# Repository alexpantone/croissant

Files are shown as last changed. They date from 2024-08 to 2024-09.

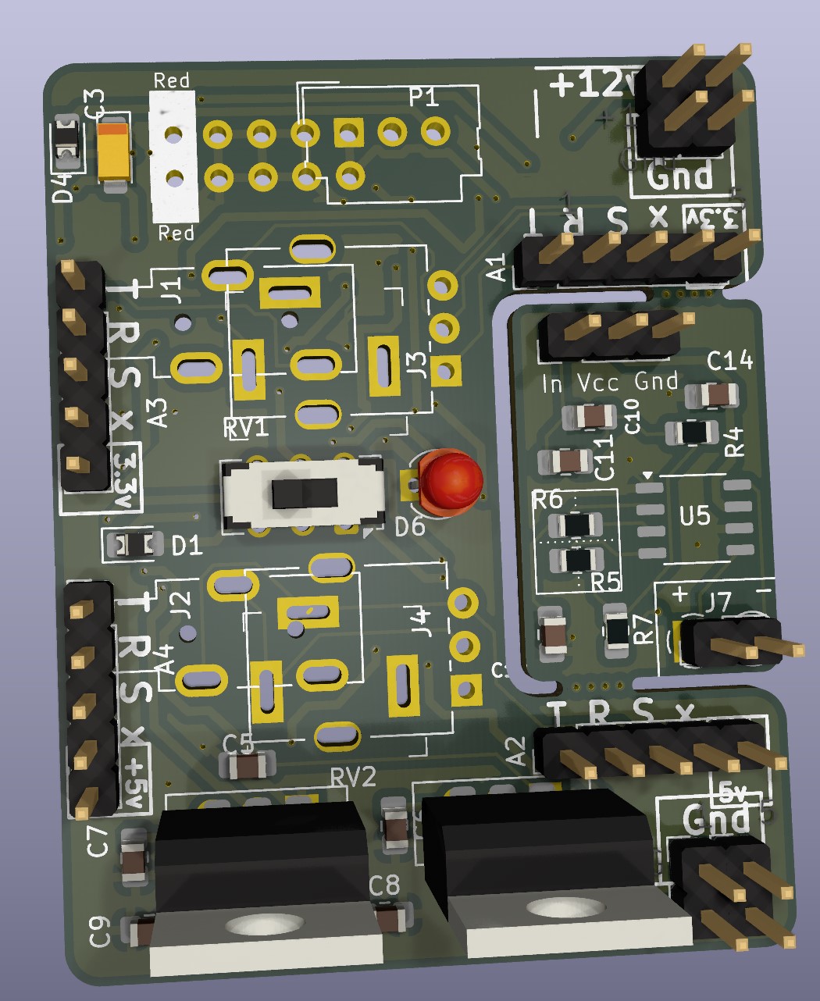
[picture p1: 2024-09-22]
Croissant Render.jpg

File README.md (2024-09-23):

# Croissant Breadboard Prototyping Tool
The Croissant is a multi-function PCB that lets you use your existing synthesizer equipment with a standard breadboard, with plenty of addons and extras.
Check out the video! [https://youtu.be/_RGXiyb1UPI?si=hu-ymMrpfnG7xpGm]

Croissant Render

One day, I was using a breadboard to test out a circuit design for my synthesizer, and I was trying to hold a headphone jack and a power connector with its cable onto the board with one hand, and another headphone jack with another hand, all while trying to turn a knob on the synth. That made me think there had to be a better way to get synthesizer components onto a breadboard, so I make just such a tool. It's shaped like a C and it goes on a breadboard, so I called it the Croissant.

The primary feature is a combined footprint for Pocket Rack (Molex SL) and Eurorack (5x2 pin shrouds) power connectors that routes +12v, Ground, and -12v to the power rails of a breadboard via pin headers. This lets you use your existing equipment on a breadboard and power it with the actual synth you will eventually use your designs in.

## Configurations
### Minimal
To use the Croissant in its most basic mode, all you need to do is add a power connector of your choice, jump the two pads labeled "0 Ohm Bypass", and install a power switch or jump the pins.
Croissant Minimal Config

### Reverse Polarity
Alternatively, you can add the capacitors and diodes for reverse polarity protection and NOT jump the 0 Ohm Bypass to guarantee your +12v and -12v lines are always just that.
Croissant Reverse Polarity

### Peripherals
In addition, the Croissant has two slots that can each fit either a vertical 3.5mm stereo jack, a horizontal jack, or a potentiometer. These connections are routed to the breadboard as well, both on the inside where the power is attached, but also on the edge of the Croissant so you can use more than one of them at a time on your breadboard.
Peripherals

### 3.3v and 5v Lines
There are also two footprints for adding two linear regulators (through-hole or surface-mount in the same footprint) and their associated capacitors. The board is labeled for 3.3v and 5v for microcontrollers such as a Raspberry Pi Pico or an Arduino.
Croissant 3_3v
Croissant 5v

### Amp
Also, since the price at most PCB fabs is the same either way, I added a small audio amplifier board to the middle of the Croissant that you can snap out. I designed it around an FM8002A based on this video: https://www.youtube.com/watch?v=I4WP1u4hwpw
I haven't tried this out myself yet, so I can't confirm if it works. I hope to soon once the parts come in. The datasheet recommended tying the positive input pin to ground and connecting the audio in to the negative input, but that sounded odd to me even if this is exclusively supposed to be an inverting amplifier. I made a footprint pattern with 0 Ohm resistors in a square where if they are soldered as the silkscreen indicates, they will produce this configuration. If these resistors are both rotate 90 degrees, that will route the audio in to the positive input of the FM8002A and tie the negative input to ground.
Amp

I only started learning PCB design a few months ago, so I'm always open to suggestions and improvements!

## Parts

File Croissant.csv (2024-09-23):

Basic Configuration |  |  |  |  |  | Notes
Reference | Value | Datasheet | Footprint | Qty | DNP
A1,A2,A3,A4 | Conn_01x05_Pin | ~ | Connector_PinHeader_2.54mm:PinHeader_1x05_P2.54mm_Vertical | 4
D6 | LED | ~ | LED_THT:LED_D3.0mm | 1 |  | Optional
P7,P8,P9,P10 | Conn_01x02_Pin | ~ | Connector_PinHeader_2.54mm:PinHeader_1x02_P2.54mm_Vertical | 4 |  | two 2x02 headers will also work
P1 | Pocket Rack Power | ~ | Connector_Molex:Molex_SL_171971-0003_1x03_P2.54mm_Vertical | 1 |  | Either a Pocket Rack (Molex SL) or a Eurorack (5x2) connector is neededm not both
P2 | Power_2x5 |  | CATs_Eurosynth:Power_2x5_Vertical | 1 |  | Either a Pocket Rack (Molex SL) or a Eurorack (5x2) connector is neededm not both
R1,R2 | 0 Ohm Bypass | ~ | Resistor_SMD:R_0805_2012Metric_Pad1.20x1.40mm_HandSolder | 2
R3 | 1k | ~ | Resistor_SMD:R_0805_2012Metric_Pad1.20x1.40mm_HandSolder | 1 |  | Only needed if installing optional LED
SW1 | Power | ~ | Button_Switch_THT:SW_CK_JS202011CQN_DPDT_Straight | 1 |  | Can be replaced with jumper wire
Reverse Polarity Protection Configuration
Reference | Value | Datasheet | Footprint | Qty | DNP
A1,A2,A3,A4 | Conn_01x05_Pin | ~ | Connector_PinHeader_2.54mm:PinHeader_1x05_P2.54mm_Vertical | 4
C1,C3 | 1u | ~ | Capacitor_Tantalum_SMD:CP_EIA-3216-10_Kemet-I_Pad1.58x1.35mm_HandSolder | 2
C2,C4 | 100n | ~ | Capacitor_SMD:C_0805_2012Metric_Pad1.18x1.45mm_HandSolder | 2
D1,D2,D3,D4 | D | ~ | Diode_SMD:D_0805_2012Metric_Pad1.15x1.40mm_HandSolder | 4
D6 | LED | ~ | LED_THT:LED_D3.0mm | 1 |  | Optional
P7,P8,P9,P10 | Conn_01x02_Pin | ~ | Connector_PinHeader_2.54mm:PinHeader_1x02_P2.54mm_Vertical | 4 |  | two 2x02 headers will also work
P1 | Pocket Rack Power | ~ | Connector_Molex:Molex_SL_171971-0003_1x03_P2.54mm_Vertical | 1 |  | Either a Pocket Rack (Molex SL) or a Eurorack (5x2) connector is neededm not both
P2 | Power_2x5 |  | CATs_Eurosynth:Power_2x5_Vertical | 1 |  | Either a Pocket Rack (Molex SL) or a Eurorack (5x2) connector is neededm not both
R3 | 1k | ~ | Resistor_SMD:R_0805_2012Metric_Pad1.20x1.40mm_HandSolder | 1 |  | Only needed if installing optional LED
SW1 | Power | ~ | Button_Switch_THT:SW_CK_JS202011CQN_DPDT_Straight | 1 |  | Can be replaced with jumper wire
5v power
Reference | Value | Datasheet | Footprint | Qty | DNP
C5 | 10uF | ~ | Capacitor_SMD:C_0805_2012Metric_Pad1.18x1.45mm_HandSolder | 1
C6 | 100nF | ~ | Capacitor_SMD:C_0805_2012Metric_Pad1.18x1.45mm_HandSolder | 1
D5 | D | ~ | Diode_SMD:D_0805_2012Metric_Pad1.15x1.40mm_HandSolder | 1
U1,U4 | LM7805 | https://www.onsemi.cn/PowerSolutions/document/MC7800-D.PDF |  | 1 |  | Either a Through-hole OR a SMD Linear regulator will fit on this footprint
3.3v Power
Reference | Value | Datasheet | Footprint | Qty | DNP
C8,C9 | 10uF | ~ | Capacitor_SMD:C_0805_2012Metric_Pad1.18x1.45mm_HandSolder | 2
C7 | 1uF | ~ | Capacitor_SMD:C_0805_2012Metric_Pad1.18x1.45mm_HandSolder | 1
U2,U3 | LD1117S33TR_SOT223 | http://www.st.com/st-web-ui/static/active/en/resource/technical/document/datasheet/CD00000544.pdf |  | 2 |  | Either a Through-hole OR a SMD Linear regulator will fit on this footprint
Peripherals
Reference | Value | Datasheet | Footprint | Qty | DNP
J1,J2,J3,J4 | AudioJack3 | ~ | -- mixed values -- | 2 |  | Any two of: Vertical headphone jack, horizontal headphone jack, or Through-hole potentiometer
RV1,RV2 | any Ohm | ~ | PersonalFootprints:Potentiometer_Vertical_Slimmer | 2
Audio Amplifier
Reference | Value | Datasheet | Footprint | Qty | DNP
C12,C14 | 1uF | ~ | Capacitor_SMD:C_0805_2012Metric_Pad1.18x1.45mm_HandSolder | 2
C10,C11 | 470n | ~ | Capacitor_SMD:C_0805_2012Metric_Pad1.18x1.45mm_HandSolder | 2
R4 | 68k | ~ | Resistor_SMD:R_0805_2012Metric_Pad1.20x1.40mm_HandSolder | 1
R5,R6 | 0 Ohm | ~ | Resistor_SMD:R_0805_2012Metric_Pad1.20x1.40mm_HandSolder | 2 |  | Place in depicted configuration to route audio to Inverting Input, rotate 98 degrees to route audio to Non-inverting Input
R7 | 20k | ~ | Resistor_SMD:R_0805_2012Metric_Pad1.20x1.40mm_HandSolder | 1
U5 | FM8002A |  | Package_SO:SOP-8_3.9x4.9mm_P1.27mm | 1

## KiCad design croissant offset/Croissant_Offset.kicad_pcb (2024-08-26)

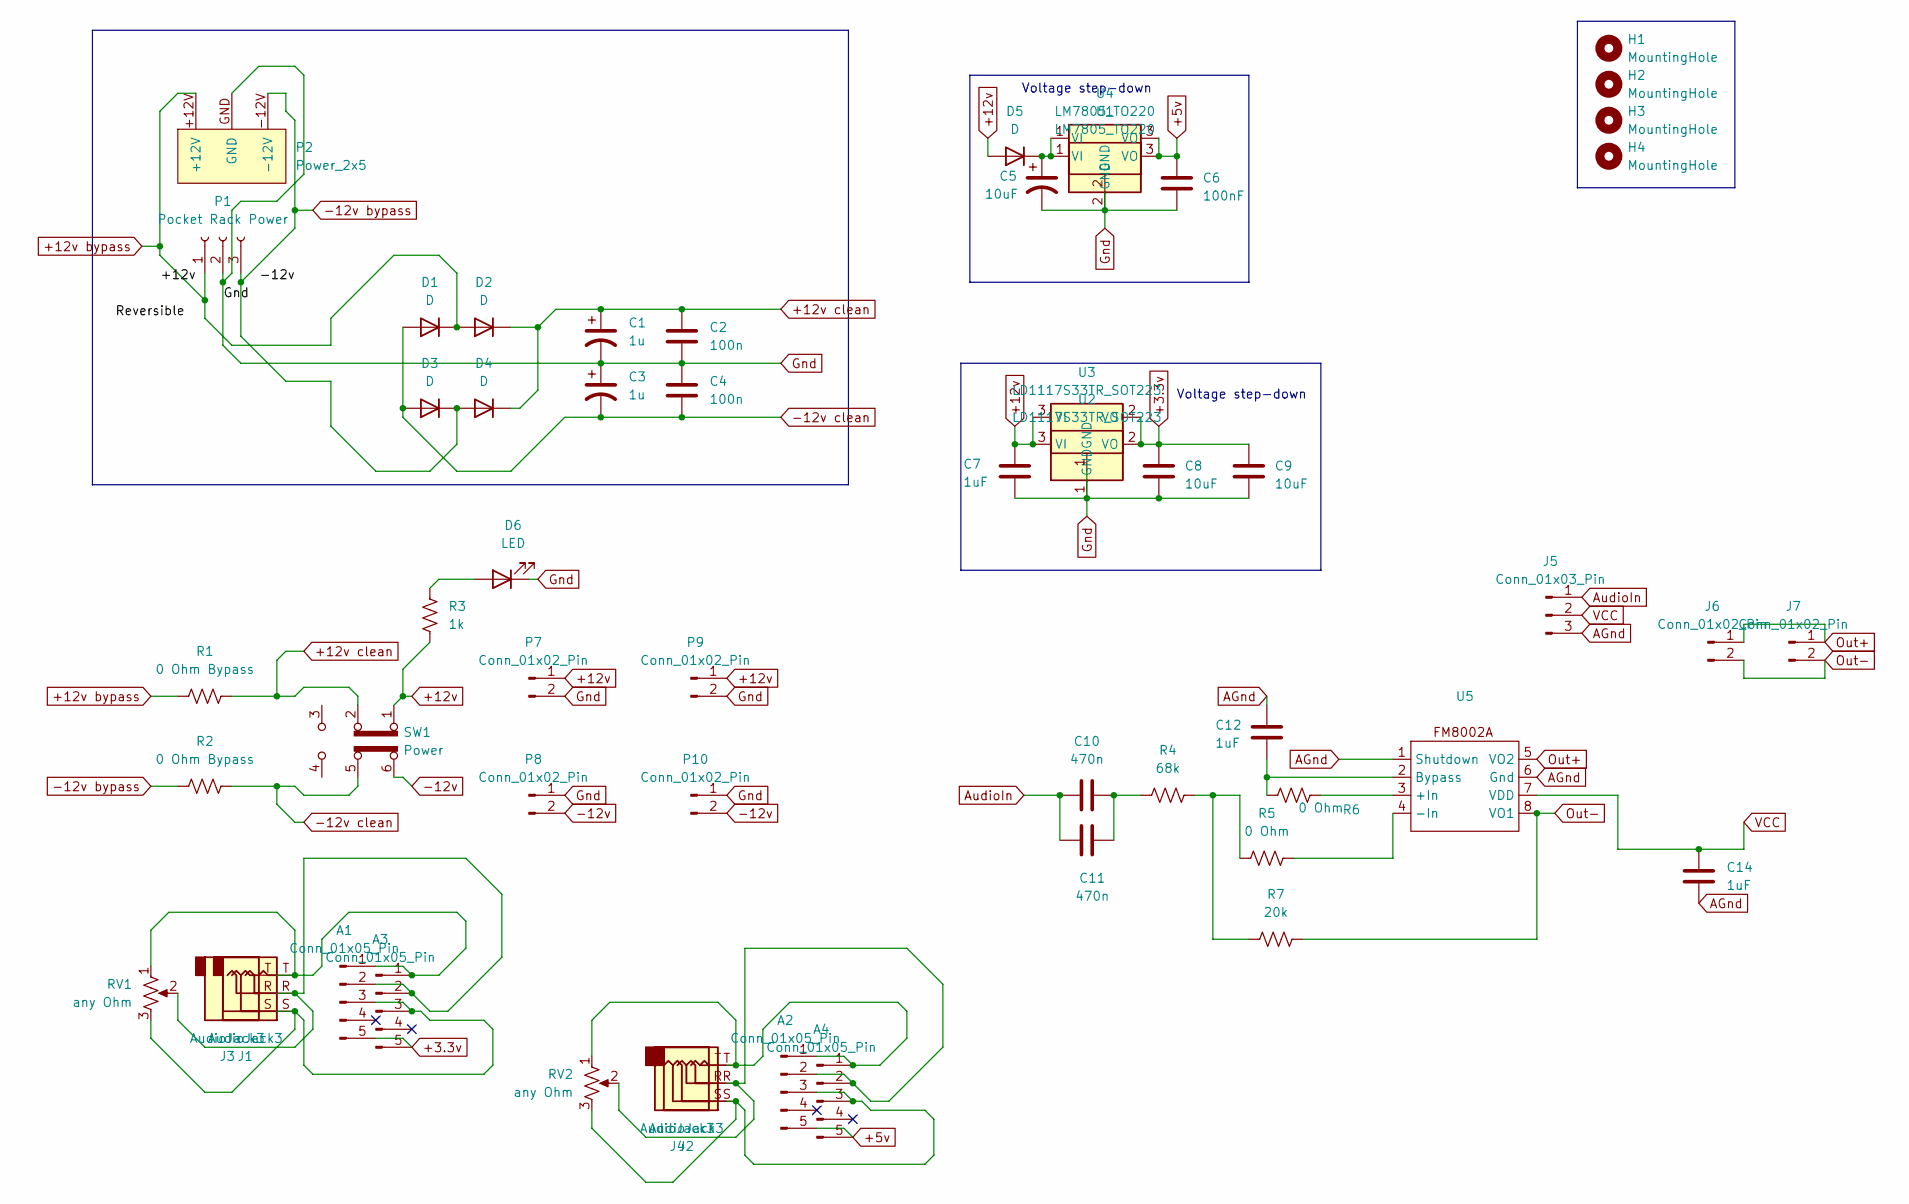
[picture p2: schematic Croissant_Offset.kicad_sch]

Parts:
A1, A2, A3, A4: Conn_01x05_Pin; PinHeader_1x05_P2.54mm_Vertical
C1, C3: 1u; CP_EIA-3216-10_Kemet-I_Pad1.58x1.35mm_HandSolder
C2, C4: 100n; C_0805_2012Metric_Pad1.18x1.45mm_HandSolder
C5, C8, C9: 10uF; C_0805_2012Metric_Pad1.18x1.45mm_HandSolder
C6: 100nF; C_0805_2012Metric_Pad1.18x1.45mm_HandSolder
C7, C12, C14: 1uF; C_0805_2012Metric_Pad1.18x1.45mm_HandSolder
C10, C11: 470n; C_0805_2012Metric_Pad1.18x1.45mm_HandSolder
D1, D2, D3, D4, D5: D; D_0805_2012Metric_Pad1.15x1.40mm_HandSolder
D6: LED; LED_D3.0mm
H1, H2, H3, H4: MountingHole; MountingHole_2.2mm_M2
J1, J2: AudioJack3; Jack_3.5mm_TRS_Horizontal
J3, J4: AudioJack3; Jack_3.5mm_QingPu_WQP-PJ301CM
J5: Conn_01x03_Pin; PinHeader_1x03_P2.54mm_Vertical
J6: Conn_01x02_Pin; PinHeader_1x02_P2.54mm_Vertical
J7: Conn_01x02_Pin; TerminalBlock_4Ucon_1x02_P3.50mm_Horizontal
P1: Pocket Rack Power; Molex_SL_171971-0003_1x03_P2.54mm_Vertical
P2: Power_2x5; Power_2x5_Vertical
P7, P8, P9, P10: Conn_01x02_Pin; PinHeader_1x02_P2.54mm_Vertical
R1, R2: 0 Ohm Bypass; R_0805_2012Metric_Pad1.20x1.40mm_HandSolder
R3: 1k; R_0805_2012Metric_Pad1.20x1.40mm_HandSolder
R4: 68k; R_0805_2012Metric_Pad1.20x1.40mm_HandSolder
R5, R6: 0 Ohm; R_0805_2012Metric_Pad1.20x1.40mm_HandSolder
R7: 20k; R_0805_2012Metric_Pad1.20x1.40mm_HandSolder
RV1, RV2: any Ohm; Potentiometer_Vertical_Slimmer
SW1: Power; SW_CK_JS202011CQN_DPDT_Straight
U1: LM7805_TO220; TO-220-3_Vertical
U2: LD1117S33TR_SOT223; TO-220-3_Vertical
U3: LD1117S33TR_SOT223; SOT-223-3_TabPin2
U4: LM7805_TO220; SOT-223-3_TabPin2
U5: SOP-8_3.9x4.9mm_P1.27mm

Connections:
+3.3v: A1.5, A3.5, C8.1, C9.1, U2.2 (VO), U3.2 (VO)
+5v: A2.5, A4.5, C6.1, U1.3 (VO), U4.3 (VO)
+12v: C7.1, D5.2 (A), P7.1, P9.1, R3.2, SW1.1 (A), U2.3 (VI), U3.3 (VI)
+12v bypass: D1.1 (K), D2.2 (A), P1.1, P2.+12V, R1.1
+12v clean: C1.1, C2.1, D2.1 (K), D4.1 (K), R1.2, SW1.2 (B)
-12v: P8.2, P10.2, SW1.6 (C)
-12v bypass: D3.1 (K), D4.2 (A), P1.3, P2.-12V, R2.1
-12v clean: C3.2, C4.2, D1.2 (A), D3.2 (A), R2.2, SW1.5 (B)
AGnd: C12.1, C14.2, J5.3, U5.1 (Shutdown), U5.6 (Gnd)
AudioIn: C10.1, C11.1, J5.1
Gnd: C1.2, C2.2, C3.1, C4.1, C5.2, C6.2, C7.2, C8.2, C9.2, D6.1 (K), P1.2, P2.GND, P7.2, P8.1, P9.2, P10.1, U1.2 (GND), U2.1 (GND), U3.1 (GND), U4.2 (GND)
unnamed: A1.1, A3.1, J1.T, J3.T, RV1.1
unnamed: A1.2, A3.2, J1.R, J3.R, RV1.2
unnamed: A1.3, A3.3, J1.S, J3.S, RV1.3
unnamed: A2.1, A4.1, J2.T, J4.T, RV2.1
unnamed: A2.2, A4.2, J2.R, J4.R, RV2.2
unnamed: A2.3, A4.3, J2.S, J4.S, RV2.3
unnamed: C10.2, C11.2, R4.1
unnamed: C5.1, D5.1 (K), U1.1 (VI), U4.1 (VI)
unnamed: D6.2 (A), R3.1
unnamed: R4.2, R5.1, R7.1
unnamed: R6.1, U5.3 (+In)
unnamed: R5.2, U5.4 (-In)
unnamed: C12.2, R6.2, U5.2 (Bypass)
Out+: J6.1, J7.1, U5.5 (VO2)
Out-: J6.2, J7.2, R7.2, U5.8 (VO1)
VCC: C14.1, J5.2, U5.7 (VDD)

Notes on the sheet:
Voltage step-down

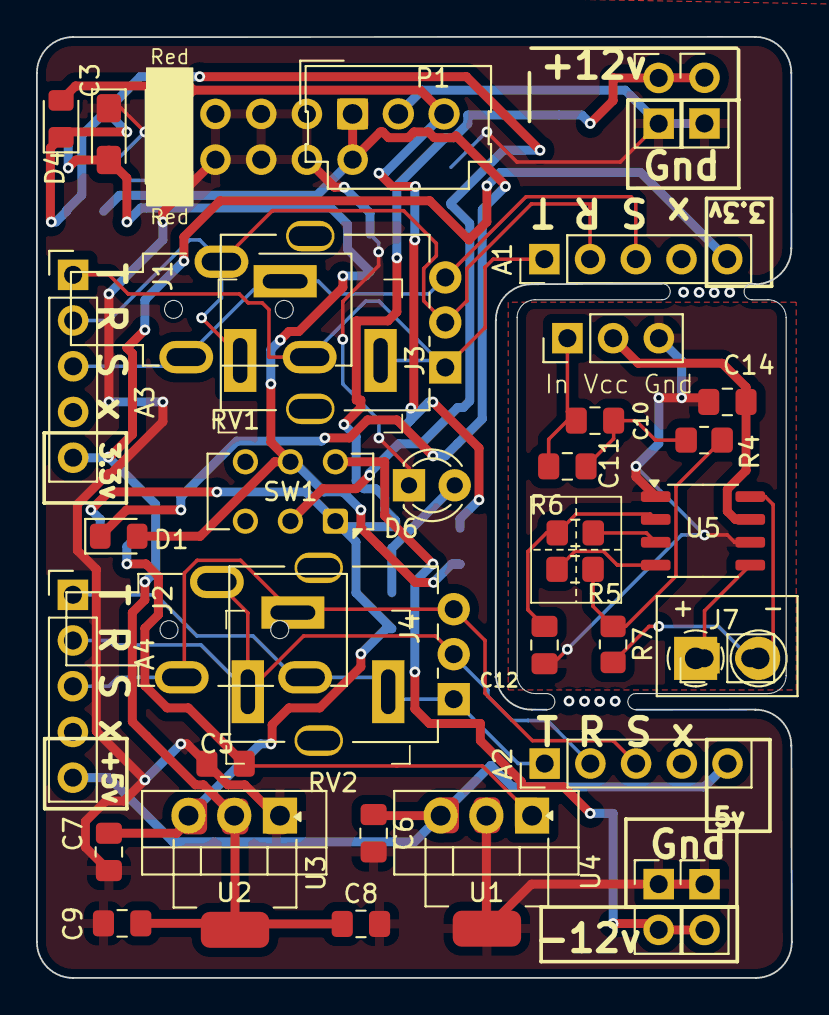
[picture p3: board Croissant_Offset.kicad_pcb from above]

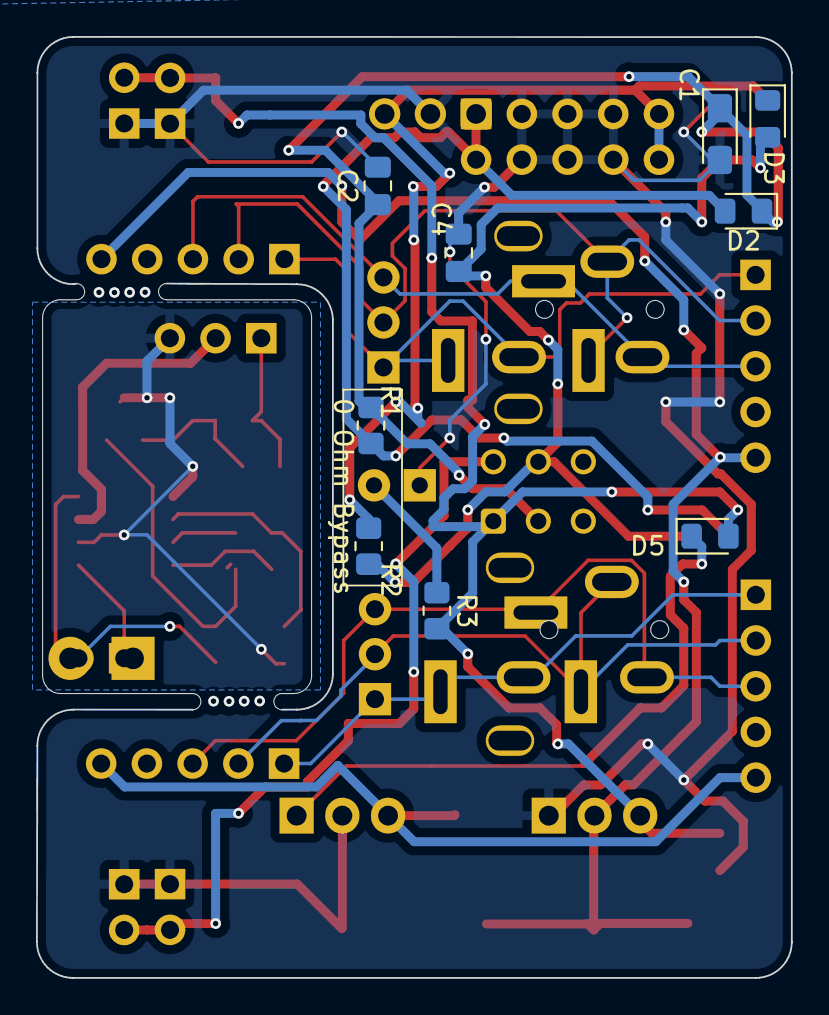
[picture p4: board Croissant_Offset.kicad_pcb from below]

Board: 2 copper layers, 41.9 x 52.3 mm, 51 parts (9 on the bottom side), 27 nets.

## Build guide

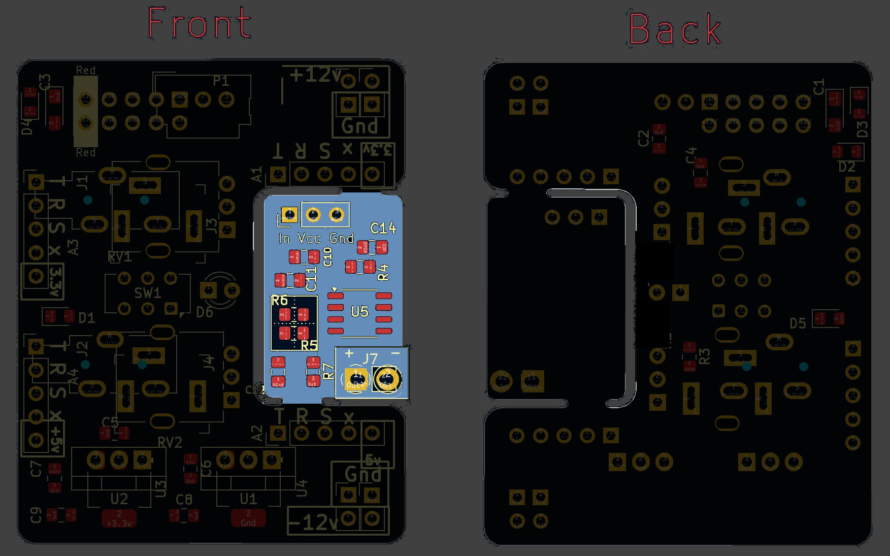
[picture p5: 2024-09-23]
Configuration Guides/Amp.jpg

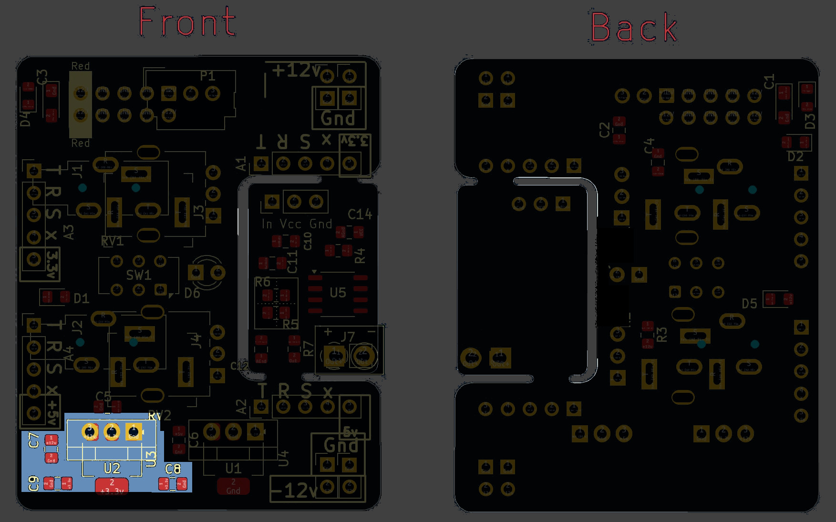
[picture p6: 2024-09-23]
Configuration Guides/Croissant 3_3v.jpg

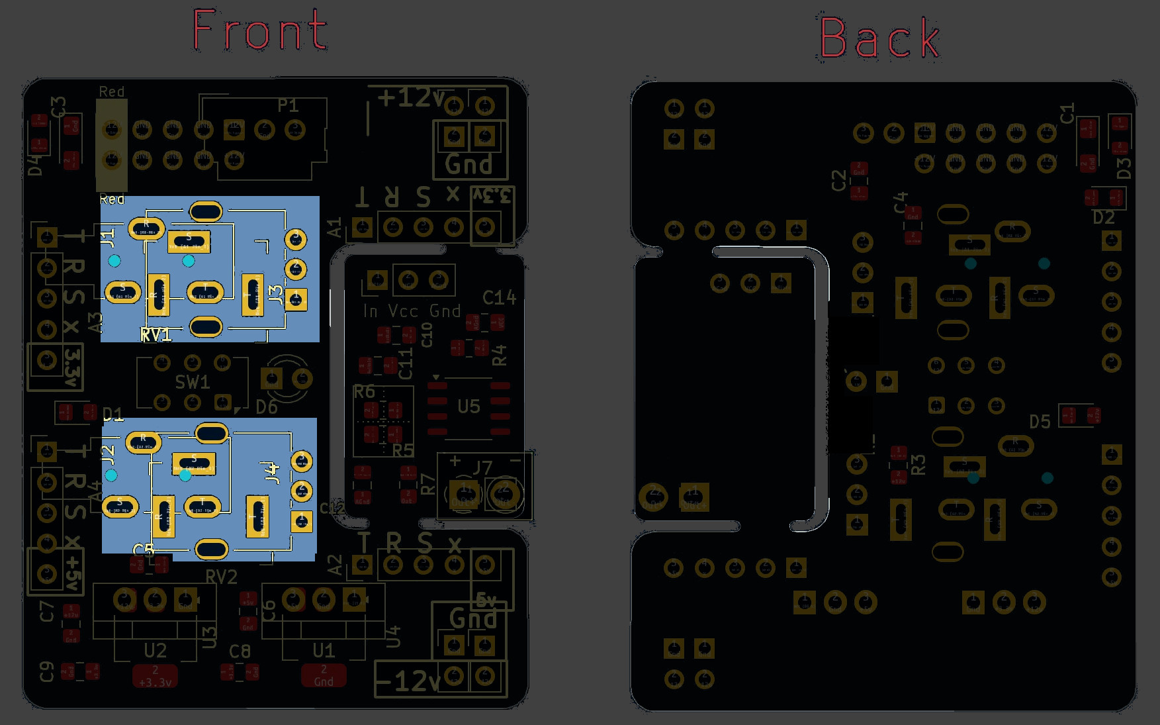
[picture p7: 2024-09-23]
Configuration Guides/Peripherals.jpg

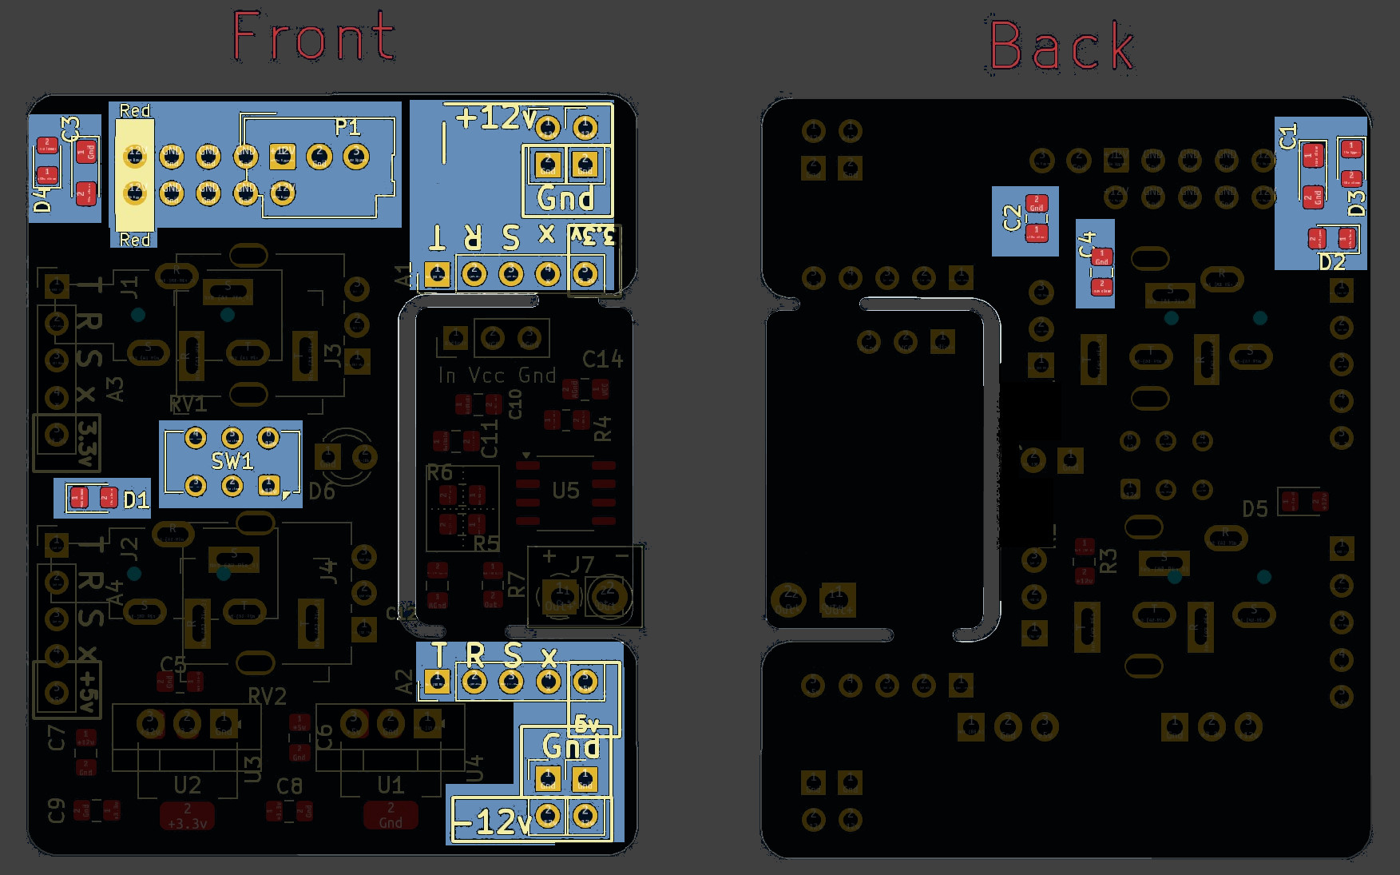
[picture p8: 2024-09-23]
Configuration Guides/Croissant Reverse Polarity.jpg

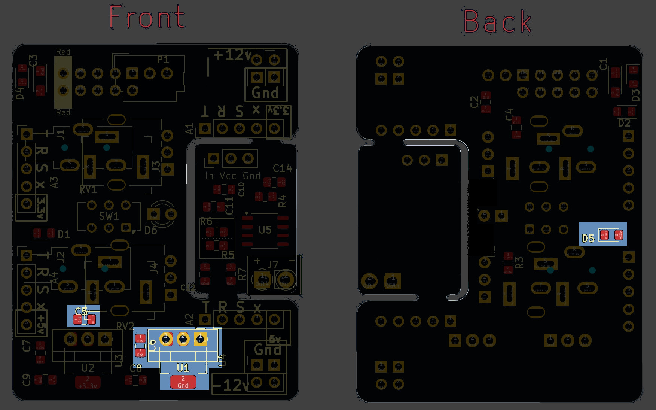
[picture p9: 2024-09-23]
Configuration Guides/Croissant 5v.jpg

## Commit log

2024-08-26 Add files via upload
    Added KiCad and Gerber files for standard breadboard
    [Croissant-B_Cu.gbr, Croissant-B_Mask.gbr, Croissant-B_Paste.gbr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]
2024-08-26 Add files via upload
    Added KiCad and gerber files for a protoboard, which is a different spacing than a breadboard.
    [Croissant_Protoboard-B_Cu.gbr, Croissant_Protoboard-B_Mask.gbr, Croissant_Protoboard-B_Paste.gbr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]
2024-08-26 Add files via upload
    KiCad and gerber files for breadboards where the power rails are offset laterally from the main body rails by one-half a pin pitch (.05").
    [Croissant_Offset-B_Cu.gbr, Croissant_Offset-B_Mask.gbr, Croissant_Offset-B_Paste.gbr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]
2024-09-22 Added BOM
    [Croissant.csv]
2024-09-22 Added render of PCB
2024-09-23 Update Croissant.csv
    Accidentally repeatedC10 and C11 in 3.3v section
    [Croissant.csv]
